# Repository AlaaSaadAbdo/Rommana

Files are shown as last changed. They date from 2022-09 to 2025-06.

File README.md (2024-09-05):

# Rommana
A 30 key well powered by Xiao BLE

### Parts
- MCU: 2x Seeeduino Xiao BLE
- On/Off Switch: 2x SS12 °F15 3 Pin On/On Mini Slide Switch
- Reset button: 2x 2 Pin DIP 6 x 6 x 5
- 30 MX switches
- Optional:
  - Ameoba PCBS
  - MX Hotswap sockets

## Pictures
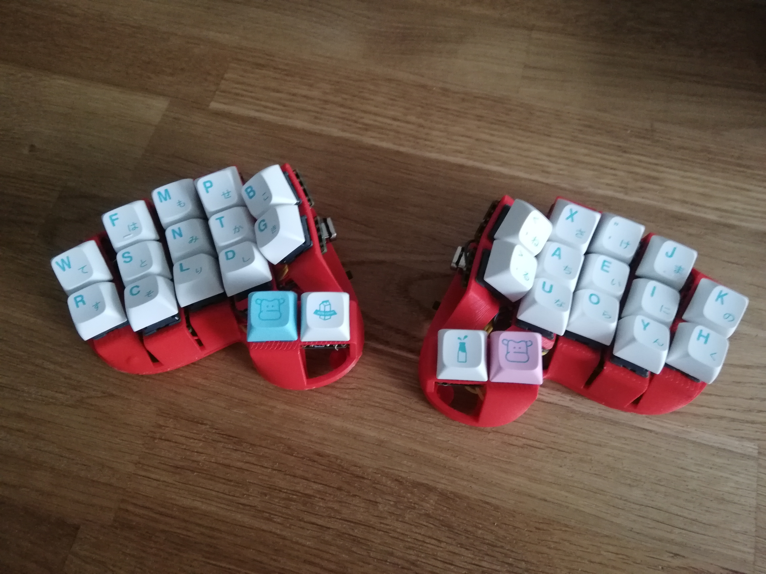
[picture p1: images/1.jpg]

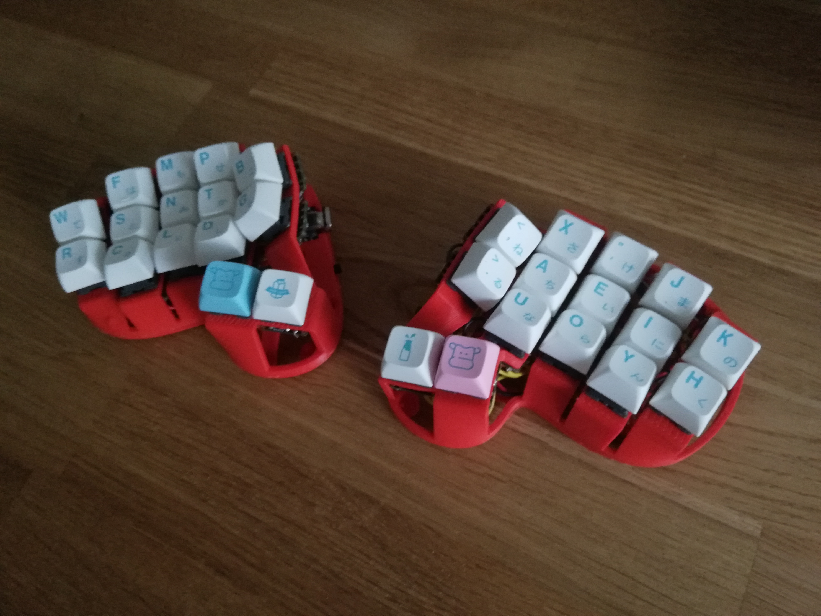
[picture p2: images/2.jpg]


## Build logs
- A hand wire by Rafael Romao: [Build Log](https://github.com/rafaelromao/keyboards/blob/main/docs/rommana.md)
- Build log with MCU holder by Oliver Säfström: [Build Log](https://github.com/safstromo/keyboards/blob/main/buildlogs/rommana/rommana.md)

## Credits and references
- This keyboard wouldn't be possible without the help and videos of [Quentin](https://github.com/bstiq) of [BastardKB](https://bastardkb.com)
- Fix the MCU holder power circuit:
  -  [safstromo](https://github.com/safstromo)
  -  [il](https://github.com/il2076)

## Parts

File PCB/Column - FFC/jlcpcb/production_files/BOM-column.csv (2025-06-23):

Comment | Designator | Footprint | LCSC
Conn_01x12_Socket | J1,J4,J6 | FPC-SMD_FPC05012-09200-.5mm-rev | C479750
1N4148 | D1,D2,D3 | D_SOD-123-rotated | C8598

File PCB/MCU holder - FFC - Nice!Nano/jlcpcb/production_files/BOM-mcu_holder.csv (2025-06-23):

Comment | Designator | Footprint | LCSC | Quantity
390 | R3,R6 | R_0805_2012Metric | C114543 | 2
180 | R2,R5 | R_0805_2012Metric | C25270 | 2
47 | R1,R4 | R_0805_2012Metric | C25315 | 2
SMLVN6RGB | D1,D2 | MHP5050RGBDT | C409780 | 2
Conn_01x12_Socket | J11,J12,J13,J14,J15,J16,J17,J2,J3 | FPC-SMD_FPC05012-09200-.5mm-rev | C479750 | 9

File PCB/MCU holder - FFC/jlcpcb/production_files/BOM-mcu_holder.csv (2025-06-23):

Comment | Designator | Footprint | LCSC
Conn_01x12_Socket | J11,J12,J13,J14,J15,J16,J17 | FPC-SMD_FPC05012-09200-.5mm-rev | C479750

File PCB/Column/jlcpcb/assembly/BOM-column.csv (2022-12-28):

Comment | Designator | Footprint | LCSC
1N4148 | D1,D2,D3 | D_DO-35_SOD27_P7.62mm_Horizontal_Reversible | C8598
Conn_01x04_Female | J5 | 4x2THT
SW_Push | SW3 | Kailh_MX-CHOC
Conn_01x04_Female | J2 | 4x2THT
SW_Push | SW2 | Kailh_hotswap_only_MX-CHOC
Conn_01x04_Female | J3 | 4x2THT
SW_Push | SW1 | Kailh_hotswap_only_MX-CHOC

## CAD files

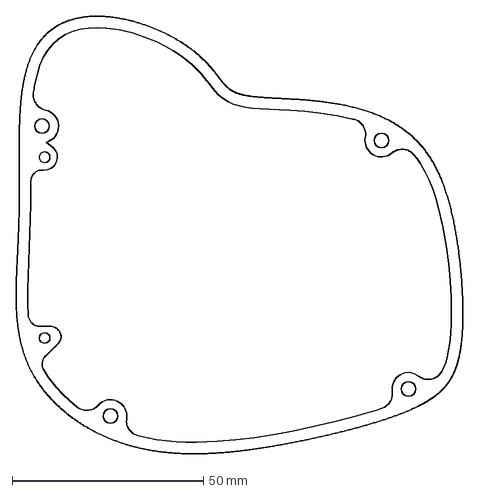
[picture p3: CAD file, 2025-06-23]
PCB/MCU holder - FFC - Nice!Nano/Bottom Plate DXF.dxf
116.8 x 114.3 mm

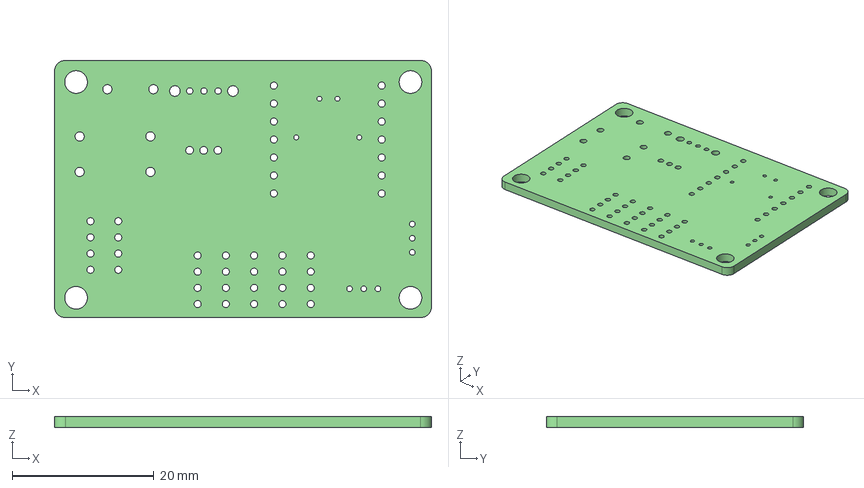
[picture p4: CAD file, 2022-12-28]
PCB/MCU holder - FFC/mcu_holder.step
53.3 x 36.3 x 1.60 mm

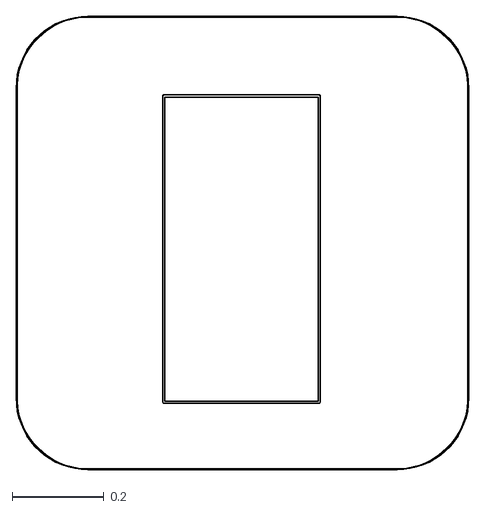
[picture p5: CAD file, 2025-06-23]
PCB/Mouse Keys/pmw3610-Edge_Cuts.dxf
0.986 x 0.987

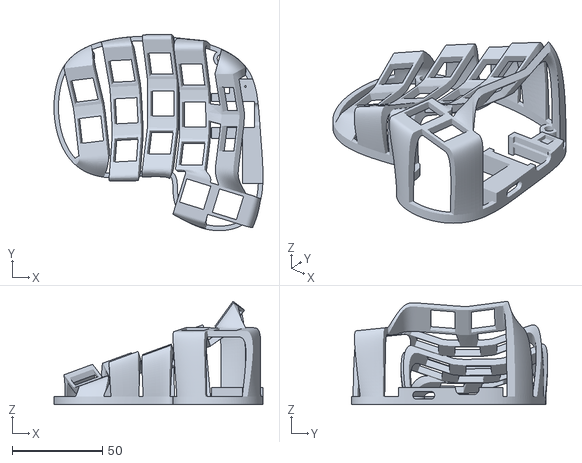
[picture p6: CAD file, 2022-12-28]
relaxed more tent/body_left.stl
115.7 x 108.6 x 57.3

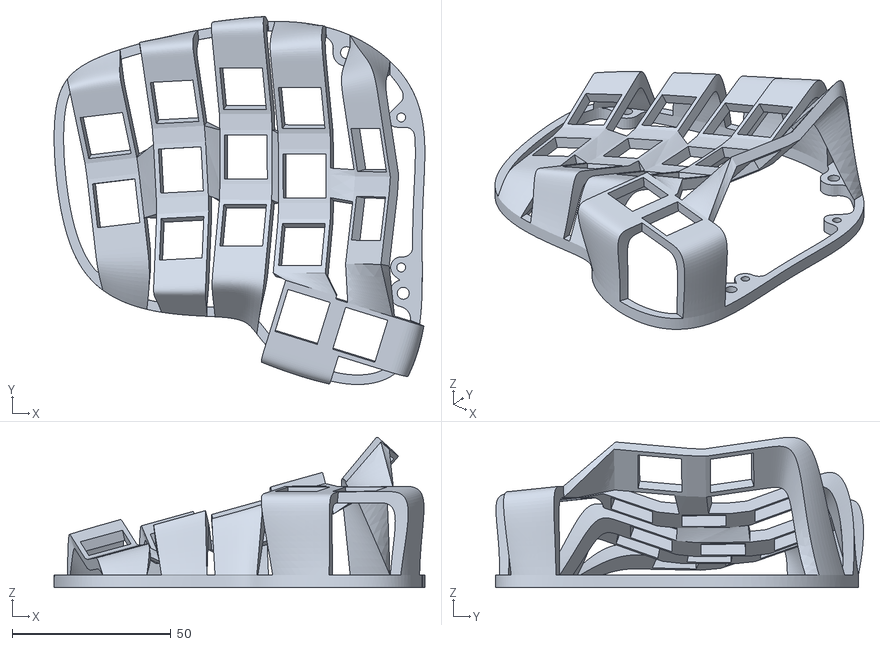
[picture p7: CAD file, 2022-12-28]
STLs/15 degree tent + flex/body_left.stl
116.7 x 115.9 x 47.4

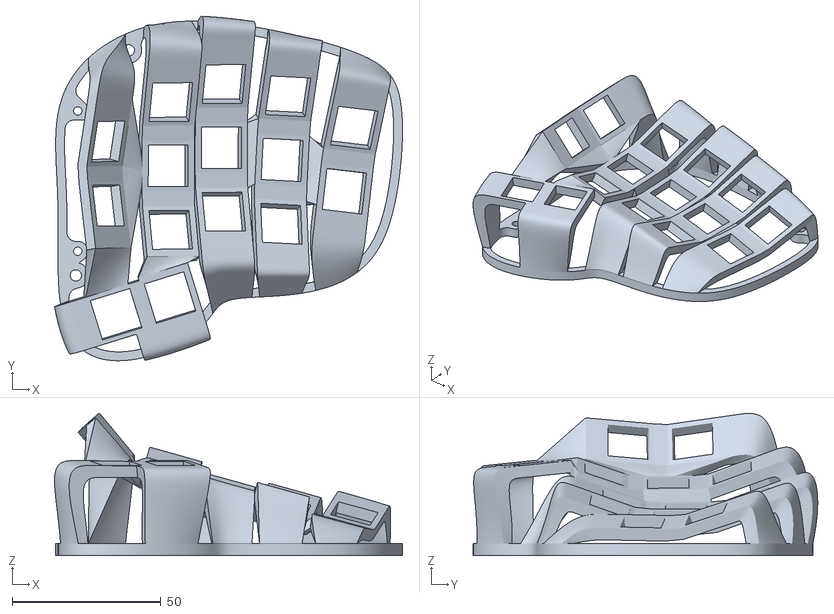
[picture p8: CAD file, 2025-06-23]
STLs/Rommana Vik/body_right.stl
117.1 x 116.0 x 47.8

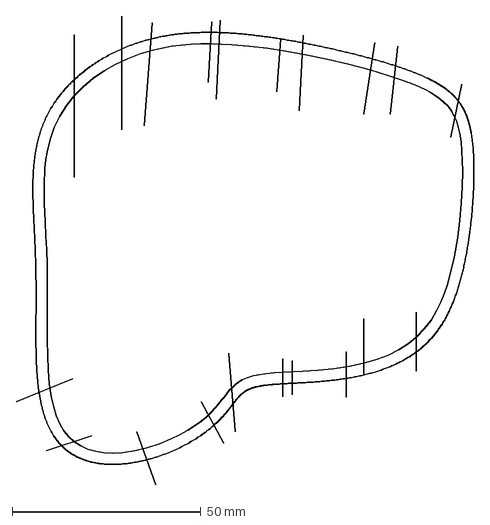
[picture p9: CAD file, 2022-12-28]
PCB/MCU holder - FFC - Nice!Nano/base-sketch.dxf
121.2 x 124.0 mm

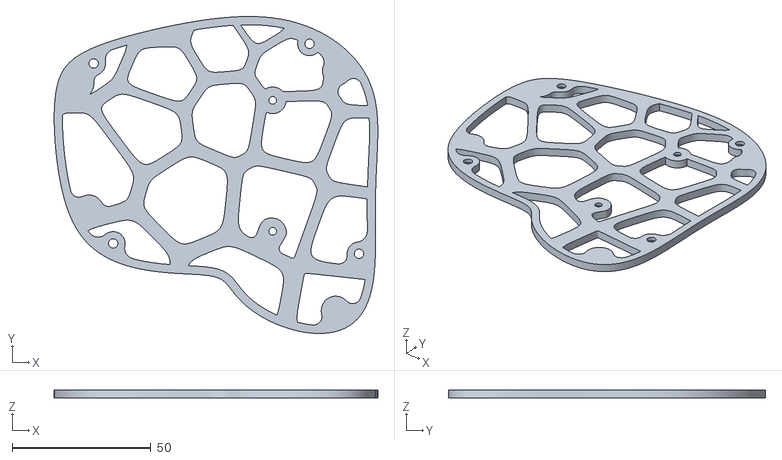
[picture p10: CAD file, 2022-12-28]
STLs/15 degree tent + flex/plate_left.stl
116.7 x 114.3 x 3.00

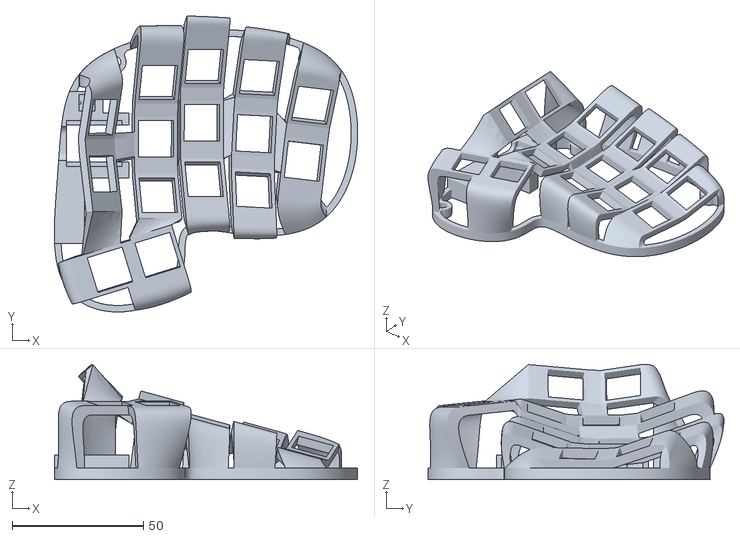
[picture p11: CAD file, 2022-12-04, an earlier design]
STLs/15 degree tent/body_right.stl
115.7 x 112.9 x 44.0

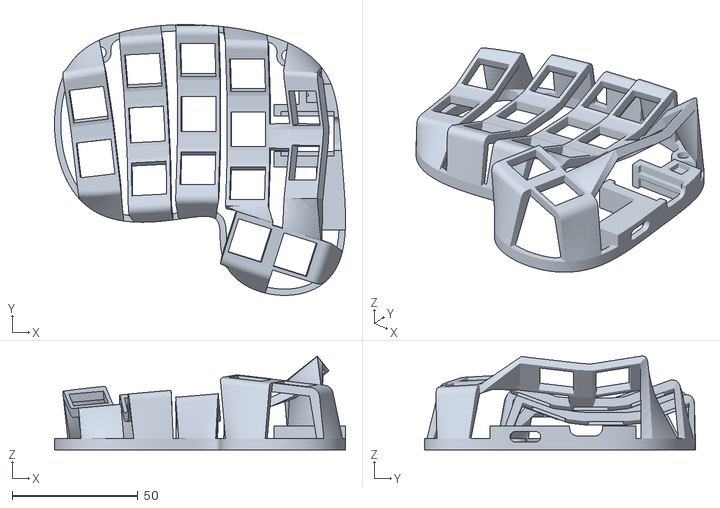
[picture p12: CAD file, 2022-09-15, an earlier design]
STLs/flat/body_left.stl
115.7 x 107.6 x 37.4

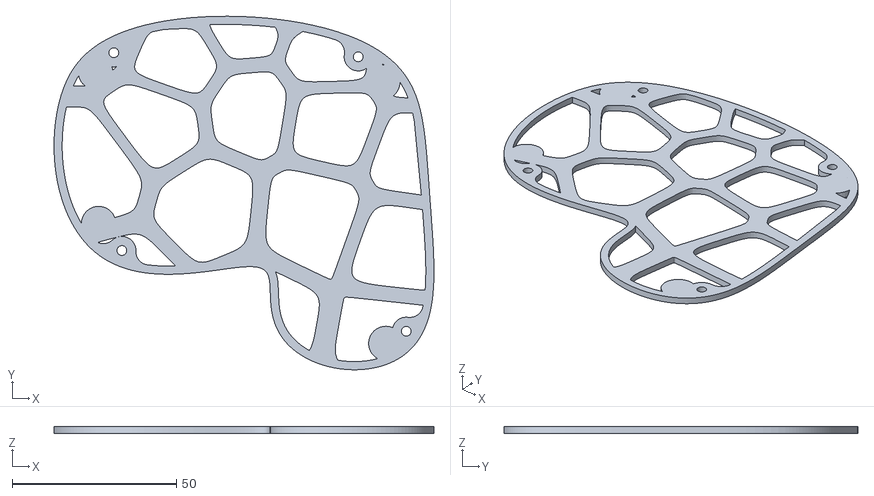
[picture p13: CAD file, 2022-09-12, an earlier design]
STLs/plate/plate_left.stl
115.7 x 107.6 x 2.00

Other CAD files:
STLs/15 degree tent + flex/body_right.stl
STLs/Rommana Vik/body_left.stl
STLs/15 degree tent + flex/plate_right.stl
STLs/15 degree tent/body_left.stl
STLs/flat/body_right.stl
STLs/plate/plate_right.stl

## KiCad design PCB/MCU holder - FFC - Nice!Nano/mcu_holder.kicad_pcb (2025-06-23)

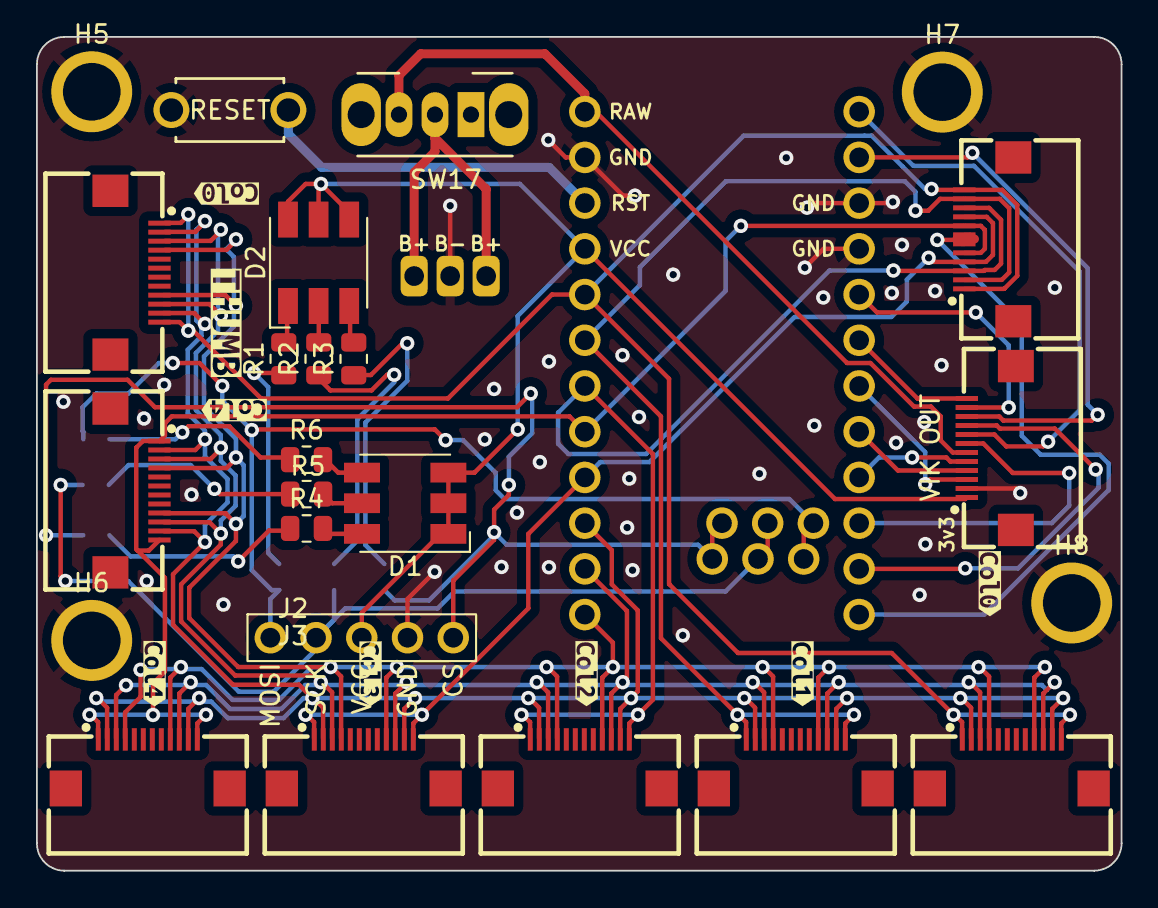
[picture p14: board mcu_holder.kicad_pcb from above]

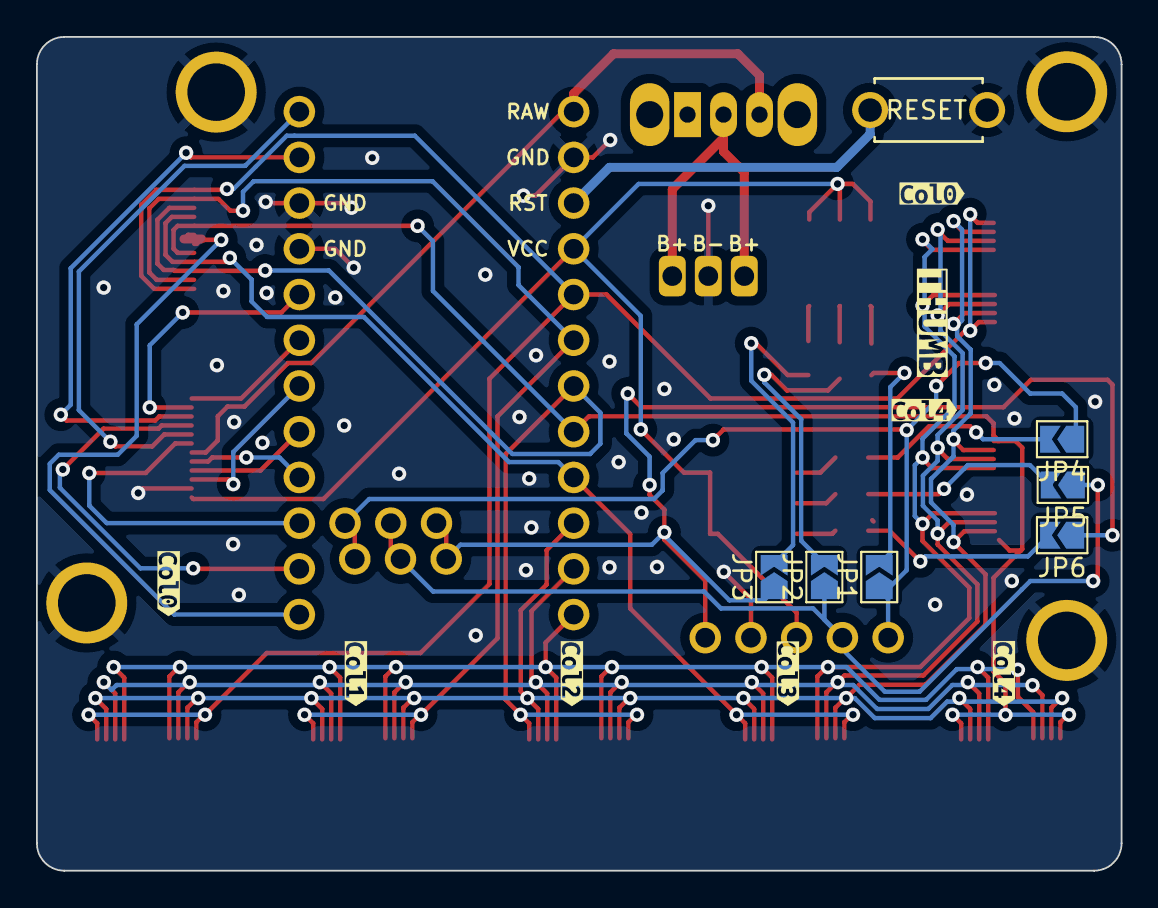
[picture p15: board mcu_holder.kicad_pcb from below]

Board: 2 copper layers, 60.3 x 46.3 mm, 48 parts (15 on the bottom side), 38 nets.

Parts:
D1: SMLVN6RGB; MHP5050RGBDT
D2: SMLVN6RGB; LED_RGB_5050-6
Display1: nice!view; nice_view
H5, H6, H7, H8: MountingHole_Pad; MountingHole_M3
J1: N!N; MCU_nice-nano
J2, J11, J12, J13, J14, J15, J16, J17: Conn_01x12_Socket; FPC-SMD_FPC05012-09200-.5mm-rev
J3: vik-keyboard-connector-horizontal
J7: Conn_01x08_Female; 3JST_BAT
JP1, JP2, JP3, JP4, JP5, JP6: Jumper_2_Open; SolderJumper-2_P1.3mm_Open_TrianglePad1.0x1.5mm
R1, R4: 47; R_0805_2012Metric
R2, R5: 180; R_0805_2012Metric
R3, R6: 390; R_0805_2012Metric
SW16: SW_Push; ResetSW
SW17: SW_SPDT; SW_CuK_OS102011MA1QN1_SPDT_Angled
kibuzzard-6399CB9D, kibuzzard-6399CB9D#2, kibuzzard-6399CB9D#3, kibuzzard-6399CB9D#4: G***; kibuzzard-6399CB9D
kibuzzard-6399CBBA, kibuzzard-6399CBBA#2: G***; kibuzzard-6399CBBA
kibuzzard-6399CBC9, kibuzzard-6399CBC9#2: G***; kibuzzard-6399CBC9
kibuzzard-6399CBD2, kibuzzard-6399CBD2#2: G***; kibuzzard-6399CBD2
kibuzzard-6399CBDB, kibuzzard-6399CBDB#2, kibuzzard-6399CBDB#3, kibuzzard-6399CBDB#4: G***; kibuzzard-6399CBDB
kibuzzard-6399CC4D, kibuzzard-6399CC4D#2: G***; kibuzzard-6399CC4D

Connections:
+3V3: D1.2 (BA), D1.4 (RA), D1.6 (GA), D2.1 (BK), D2.3 (RK), D2.5 (GK), Display1.3 (VCC), J1.21 (3V3), J3.1 (3V3)
B: JP1.2 (B), R1.1
B2: JP4.2 (B), R6.1
BAT+: J7.1, J7.3, SW17.2 (B)
BATT_OR_5V: J1.24 (BAT), J3.6 (5V), SW17.3 (C)
G: JP2.2 (B), R2.1
G2: JP5.2 (B), R5.1
GND: Display1.4 (GND), H5.1, H6.1, H7.1, H8.1, J1.3 (GND), J1.4 (GND), J1.23 (GND), J3.2 (GND), J7.2, SW16.2
GPIO_AD1: J1.10 (011), J3.7 (GPIO_AD1)
GPIO_AD2: J1.11 (104), J3.9 (GPIO_AD2)
MISO: J1.5 (017), J3.11 (MISO)
MOSI: J1.1 (006), J3.8 (MOSI)
NVCS: Display1.5 (CS), J1.33 (107), JP3.1 (A), JP6.1 (A)
NVMOSI: Display1.1 (MOSI), J1.31 (101), JP1.1 (A), JP4.1 (A)
NVSCK: Display1.2 (SCK), J1.32 (102), JP2.1 (A), JP5.1 (A)
unnamed: D1.1 (BK), R4.2
unnamed: D1.5 (GK), R6.2
unnamed: D1.3 (RK), R5.2
unnamed: D2.2 (BA), R1.2
unnamed: D2.6 (GA), R3.2
unnamed: D2.4 (RA), R2.2
R: JP3.2 (B), R3.1
R2: JP6.2 (B), R4.1
RESET: J1.22 (RST), SW16.1
RGB_LED_OUT: J1.9 (100), J3.5 (RGB_LED_OUT)
SCL: J1.8 (024), J3.4 (SCL)
SCLK: J1.6 (020), J3.12 (SCLK)
SDA: J1.7 (022), J3.3 (SDA)
SPI_CS: J1.2 (008), J3.10 (SPI_CS)
col0: J1.20 (031), J2.1, J2.12, J15.1, J15.12, J16.1, J16.12
col1: J1.19 (029), J2.2, J2.11, J11.1, J11.12
col2: J1.18 (002), J2.3, J2.10, J12.1, J12.12
col3: J1.16 (113), J2.4, J2.9, J13.1, J13.12
col4: J1.17 (115), J2.5, J2.8, J14.1, J14.12, J17.1, J17.12
row_0: J1.15 (111), J11.2, J11.11, J12.2, J12.11, J13.2, J13.11, J14.2, J14.11, J15.2, J15.11, J16.2, J16.11, J17.2, J17.11
row_1: J1.14 (010), J11.3, J11.10, J12.3, J12.10, J13.3, J13.10, J14.3, J14.10, J15.3, J15.10, J16.3, J16.10, J17.3, J17.10
row_2: J1.13 (009), J11.4, J11.9, J12.4, J12.9, J13.4, J13.9, J14.4, J14.9, J15.4, J15.9, J16.4, J16.9, J17.4, J17.9
row_3: J1.12 (106), J2.6, J2.7

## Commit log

2022-09-15 Improve middle/ring/pinky position
    [body_left.stl, body_right.stl]
2022-09-17 add tented version
    [body_left.stl, body_right.stl, plate_left.stl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]
2022-12-04 improved column support in 15 degree tented
    [body_left.stl, body_right.stl]
2022-12-28 flex pcb and body for for it
    [BOM-column.csv, BOM-mcu_holder.csv, base-sketch.dxf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]
2024-04-17 fix mcu holder power circuit
    [mcu_holder.kicad_pcb, mcu_holder.kicad_sch]
2024-04-17 credits for MCU power circuit fix
2025-06-23 Rommana FFC version
    [BOM-column.csv, BOM-mcu_holder.csv, Bottom Plate DXF.dxf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]
